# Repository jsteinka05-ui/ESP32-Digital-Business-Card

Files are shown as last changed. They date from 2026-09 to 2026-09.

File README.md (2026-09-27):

# ESP32 Digital Business Card

A standalone digital business card built around a **Seeed Studio XIAO ESP32-C3** and a **3.5-inch ILI9488 SPI TFT display**. This repository documents its hardware and a firmware rewrite in **C using ESP-IDF**.

The device is designed to display personal contact information and a LinkedIn QR code, with a single button for slide navigation, display recovery, and wake-up.

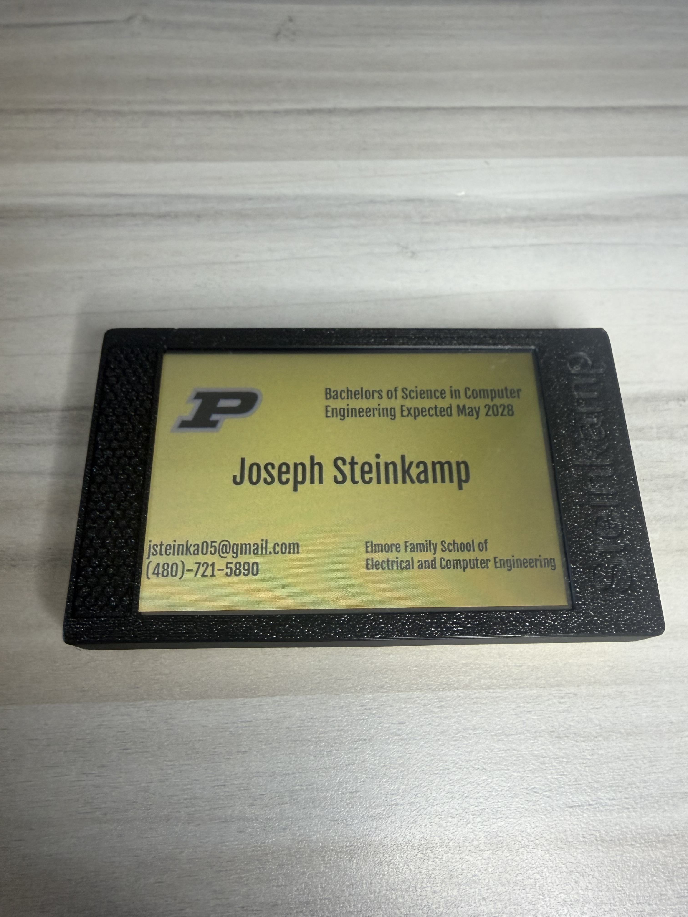
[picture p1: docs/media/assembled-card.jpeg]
Assembled digital business card displaying contact information in its printed enclosure


[Watch the device demonstration](docs/media/device-demo.mp4) — slide transitions, LCD power switching, and display recovery.

## Project Status

The custom PCB assembly, wiring, printed enclosure, and C firmware rewrite are complete. The ESP-IDF v6.1 firmware supports debounced button input, embedded slides, animated navigation, LCD recovery, and five-minute inactivity sleep with button wake.

Functional hardware checks and a clean-checkout build are complete. Recorded results include five startup draws at 238 ms each and twenty transitions averaging 2,604.75 ms, with unchanged sampled free heap. See the [validation record](docs/testing.md) for methods and limits. Current consumption and physical wake latency are outside this release's measurement scope.

Hardware design files and printable enclosure models are available under [hardware/](hardware/README.md).

## Features

- Business-card and LinkedIn QR-code slides.
- Standalone operation with images embedded in firmware; no network connection or SD card required.
- Animated transitions controlled by a physical button.
- Long-press recovery after the LCD is power-cycled independently of the microcontroller.

- Low-power idle after five minutes without button input.
- Button wake-up that restores the current slide without advancing it.

The current backlight is powered directly from the display supply. Automatic backlight shutdown would require a hardware change. Wi-Fi and Bluetooth Low Energy are future expansion options.

## Hardware and Design Choices

| Part | Purpose |
|---|---|
| Seeed Studio XIAO ESP32-C3 | Compact controller with flash storage, SPI, and room for wireless expansion |
| 3.5-inch ILI9488 SPI TFT | Color contact-information and QR-code display |
| Momentary pushbutton | Navigation, display recovery, and wake-up |
| LCD power switch | Controls LCD power independently of the microcontroller |

The ESP32-C3 can be considered overkill for displaying two images and reading a button. I chose it to leave room for future Wi-Fi and Bluetooth Low Energy functionality without replacing the controller.

Embedded images keep the initial storage design simple, while SPI limits the display wiring. The tradeoffs include flash usage, display-update bandwidth, and the need to rebuild firmware when artwork changes.

See the [design document](docs/design.md) for component rationale, wiring, memory calculations, and power-management considerations.

## Intended Controls

The firmware rewrite targets the following controls, including sleep and wake behavior:

| Input or condition | Intended behavior |
|---|---|
| Short press: less than 900 ms | Advance to the next slide upon release |
| Long press: at least 900 ms | Reinitialize the LCD and redraw the current slide upon release |
| Five minutes without button input | Enter a low-power idle state |
| Button press while idle | Wake and restore the current slide; consume the gesture without navigation |

The LCD switch leaves the ESP32-C3 running. Display recovery is needed because restoring LCD power does not automatically repeat the panel initialization sequence.

Button-only wake-up assumes the LCD supply switch remains on. If the LCD is manually switched off, restore its power before waking the device or requesting display recovery.

## Repository Layout

```text
firmware/                 ESP-IDF application and build configuration
    main/                 Application logic
    components/ili9488/   Display driver
    images/               Source artwork and display assets
    tools/                Image conversion utilities
hardware/                 Hardware documentation
    schematic/            KiCad project, PCB, schematic, and local libraries
    manufacturing/        Versioned Gerber and drill packages
    enclosure/            Printable STL models and enclosure notes
docs/                     Design decisions and testing documentation
.github/workflows/        Future automated build checks
```

## Development Setup

The intended development environment is:

- VS Code with Espressifâ€™s ESP-IDF extension.
- ESP-IDF with the ESP32-C3 target and its toolchain.
- A USB data connection to the XIAO ESP32-C3.
- Python with Pillow for artwork conversion; the saved RGB assets allow firmware builds without Pillow.

Firmware development takes place under `firmware/`. The application includes debounced input, streamed image drawing, and slide navigation. The [progress log](docs/progress.md) distinguishes implemented features from verified hardware behavior.

## Roadmap

- [x] Establish repository structure and ignore rules.
- [x] Document the initial design.
- [x] Complete prototype wiring, custom PCB assembly, and printed enclosure.
- [x] Organize KiCad files, manufacturing exports, and enclosure models.
- [x] Implement startup logging and debounced button input.
- [x] Initialize the display and verify drawing, colors, and orientation.
- [x] Display embedded slides and implement navigation.
- [x] Add LCD recovery and animated transitions.
- [x] Implement inactivity sleep and button wake-up.
- [x] Verify sleep/wake on hardware.
- [x] Publish build instructions, test results, and a device demonstration.

## Documentation

- [Firmware rewrite design](docs/design.md): architecture, hardware selection, interaction rules, and validation plan.
- [Firmware validation](docs/testing.md): build checks, simulated button tests, and hardware results.
- [Firmware development plan](docs/firmware-plan.md): implementation stages and completion criteria.
- [Hardware](hardware/README.md): KiCad project, parts inventory, and manufacturing revisions.
- [Enclosure](hardware/enclosure/README.md): top case, bottom case, and button models.
- [Progress and commit log](docs/progress.md): milestones, checks, and commit references.

## License

Third-party library sources and licensing are listed in the [library documentation](hardware/schematic/libraries/README.md), with the upstream license included alongside its files.

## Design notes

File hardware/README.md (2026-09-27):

# Hardware

The digital business card uses a custom PCB and a three-part printed enclosure. PCB assembly, wiring, and the physical prototype are complete.

## Directory Layout

```text
schematic/
    Project_Buisiness_Card.kicad_pro  KiCad project
    Project_Buisiness_Card.kicad_sch  Circuit schematic
    Project_Buisiness_Card.kicad_pcb  PCB layout
    fp-lib-table                    Footprint libraries
    sym-lib-table                   Symbol libraries
    Library.pretty/                 Custom footprint library
    libraries/                      XIAO symbols and footprints
manufacturing/
    Buisiness_Card_Gerbers_1.2.zip
    Buisiness_Card_Gerbers_1.3.zip
    Project_Buisiness_Gerbers_1.4.zip
enclosure/
    Top_Case.stl
    Bottom_Case.stl
    Button (1).stl
```

The schematic, PCB, and project settings share a directory and base name so KiCad can associate them as one project.

## KiCad Project

Open [Project_Buisiness_Card.kicad_pro](schematic/Project_Buisiness_Card.kicad_pro) in KiCad 9.0. The XIAO libraries are stored locally and use project-relative paths.

The PCB uses a custom through-hole XIAO footprint. The original surface-mount footprint is available under a separate library name. The active assignment uses the through-hole version.

[Library documentation](schematic/libraries/README.md) describes the footprint variants, project assignments, and upstream sources.

## Fabricated PCB

Bare revision 1.4 PCB before component installation. The component side shows the XIAO footprint, display header, passive-component positions, and button and power-switch connections.

| Component side | Reverse side |
|---|---|
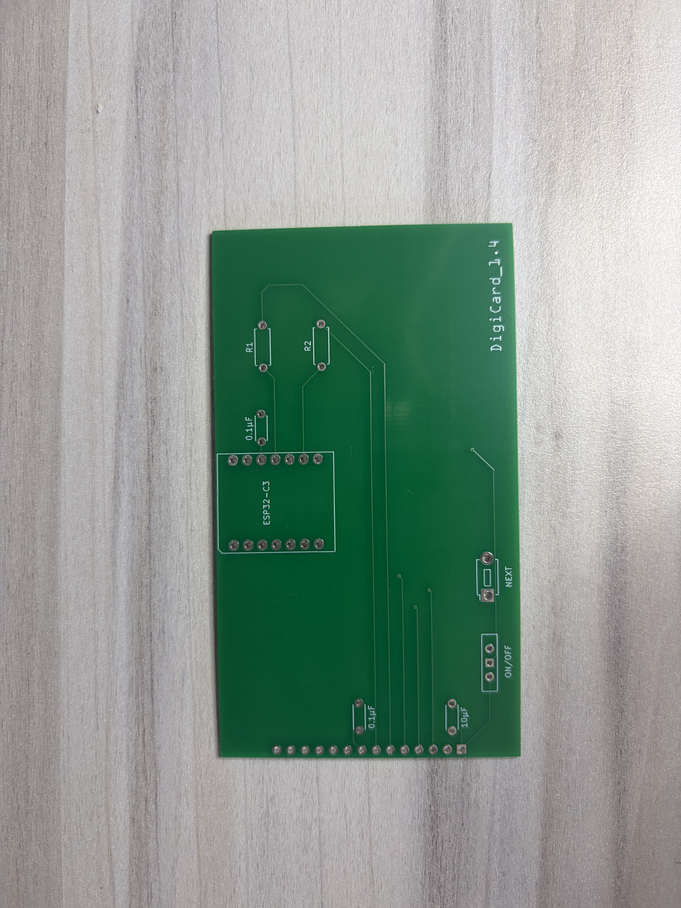
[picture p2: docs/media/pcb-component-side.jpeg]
Bare revision 1.4 PCB component side with labeled through-hole footprints
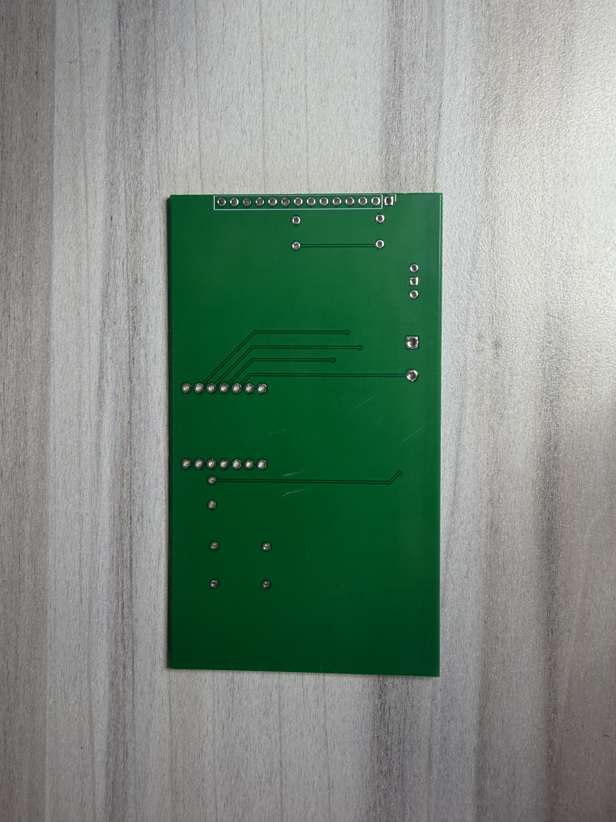
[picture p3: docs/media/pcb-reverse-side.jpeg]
Reverse side of the bare PCB showing routing and through-hole pads
|  |  |

## Manufacturing Files

Version **1.4** is the current hardware revision. Versions 1.2 and 1.3 are retained as earlier exports. Each archive contains Gerber layers and plated/non-plated drill files.

## Enclosure

The enclosure consists of a [top case](enclosure/Top_Case.stl), [bottom case](enclosure/Bottom_Case.stl), and [button](<enclosure/Button (1).stl>).

See the [enclosure documentation](enclosure/README.md) for the printable models.

## Components

| Component | Quantity | Function |
|---|---:|---|
| Seeed Studio XIAO ESP32-C3 | 1 | Display control and button processing |
| 3.5-inch ILI9488 SPI TFT | 1 | Contact-information and QR-code display |
| SPST slide switch | 1 | LCD power control |
| Momentary pushbutton | 1 | Slide navigation and display recovery |
| 1 × 14 header, 2.54 mm pitch | 1 | LCD connection |

## Schematic Values and Footprint Assignments

These entries describe the KiCad design. Switch model names identify the assigned footprints.

| Reference | Schematic value | Footprint |
|---|---|---|
| U1 | XIAO ESP32C3 | Project-specific through-hole XIAO footprint |
| SW1 | SW_SPST | Wuerth WS-SLTV slide-switch footprint |
| SW2 | SW_Push | APEM MJTP1243 pushbutton footprint |
| J_LCD1 | Conn_01x14 | 1 × 14 pin header, 2.54 mm pitch |
| J_BAT1 | Two-pin connector | — |
| C1, C3 | 0.1 µF | Radial capacitor, 5 mm lead spacing |
| C2, C4 | 10 µF | Radial capacitor, 5 mm lead spacing |
| R4, R6 | `46` | Axial resistor, 7.62 mm lead spacing |

The [design specification](../docs/design.md#existing-prototype-wiring) contains the GPIO mapping and LCD power behavior.

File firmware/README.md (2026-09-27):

# Firmware

C firmware for the Seeed Studio XIAO ESP32-C3, developed with ESP-IDF v6.1.

## Current Behavior

At startup, the application initializes the LCD, validates both embedded images, and displays the business card. A short release advances with a black wipe and shuffled tile reveal. A long release reinitializes the LCD and redraws the selected slide without advancing it. The previous slide firmware and QR appearance were tested on the board; this recovery/animation version has been flashed and passed hardware checks for recovery, transitions, gesture suppression, QR scanning, and timing.

The button module configures GPIO6 as an input with an internal pull-up. The application accepts transitions after 30 ms of stable input. It samples once per loop, with a 10 ms task delay plus any drawing work. Animation steps are bounded; actual sampling gaps are logged for hardware measurement.

| Serial message | Meaning |
|---|---|
| `Button input ready` | GPIO initialization succeeded |
| `Button pressed` | A press passed the debounce interval |
| `Short press released` | A tracked press lasted less than 900 ms |
| `Long press released` | A tracked press lasted at least 900 ms |
| `Button released (no tracked press)` | A button held at startup was released without generating a gesture |

Durations are measured between accepted press and release transitions. A tracked release emits the short or long event instead of a separate release event. Holding never repeatedly emits a gesture. The first reading establishes state without generating a button event.

The button module returns events; the application controller decides whether to start a transition or recover the LCD. Accepted events during animation update the activity timestamp but never queue navigation or recovery. After startup, animation, or recovery, input must remain released for 30 ms before another gesture is accepted. After 300 seconds without accepted input, the power manager requests panel sleep and enters ordinary light sleep. Hardware sleep/wake validation is complete.

Normal transitions return to button sampling after one eight-row wipe strip or at most sixteen 8 x 8 tiles. The next step is eligible after 10 ms; a delayed loop never catches up with an unbounded batch. Each reveal covers all 2,400 tiles once. The selected slide changes only after the last tile succeeds.

Panel reset delays, startup drawing, and recovery drawing remain synchronous. A complete gesture during those operations can be missed; a held button is consumed until release. Drawing errors stop the transition and preserve the selected index. The screen may remain partial until a later successful transition or long-press recovery.

## Inactivity and Wake

The inactivity interval starts after the initial image is drawn. Accepted button events restart it, including events suppressed during animation. Sleep is deferred while a button is held, input is blocked, or rendering is active.

At timeout, the panel receives display-off and sleep-in commands. The application keeps polling for 120 ms while the panel settles. A press during that interval cancels sleep and restores the selected slide. Otherwise, the ESP32-C3 enters ordinary light sleep with active-low GPIO6 wake and its pull-up retained. Peripheral power-down sleep is not supported by this configuration.

Wake reinitializes the panel on the existing SPI bus and redraws the selected slide. The wake gesture is consumed until the button has remained released for 30 ms, even if held longer than 900 ms. The inactivity timer restarts after restoration. A rejected sleep attempt also restores the panel; errors are logged and the timeout restarts rather than retrying continuously.

The backlight remains powered because it is wired directly to the display supply. The manual LCD switch must remain on for button-only wake. Current consumption and physical wake latency are outside this release's measurement scope. The logged redraw time covers panel initialization and drawing, not the complete physical wake latency.

## Build, Flash, and Monitor

Install ESP-IDF v6.1 with the ESP32-C3 tools. In VS Code, open this `firmware` directory, select the installed ESP-IDF environment, and open an ESP-IDF terminal here.

```text
idf.py build
idf.py -p <PORT> flash monitor
```

Replace `<PORT>` with the board's serial port selected through `ESP-IDF: Select Port to Use`. On Windows this is a COM port; its number varies by computer. Close other serial monitors before flashing. Exit the monitor with Ctrl+].

The project selects the ESP32-C3 target. `sdkconfig.defaults` specifies 4 MB flash, the USB Serial/JTAG console, and the custom partition table. `partitions.csv` provides a 2 MB factory application partition for code and embedded images. The remaining flash is unallocated; OTA is not configured. Flashing replaces the firmware currently on the board.

Existing checkouts with a generated `sdkconfig` retain their old settings. In `idf.py menuconfig`, select **Partition Table > Custom partition table CSV** and use `partitions.csv`, then rebuild. Flash with `idf.py flash` so the updated partition table is written along with the application.

## Images and Diagnostics

Both source PNGs and generated RGB files are tracked in [images/](images/README.md). Conversion is a separate step, so building saved assets does not require Pillow. After editing artwork, regenerate the matching RGB file before building.

To run the earlier color and corner checks, enable **Business card > Run display diagnostics before showing slides** in `idf.py menuconfig`. The corner pattern remains visible for five seconds before the business-card slide appears. This option defaults off.

Startup logs the initial drawing duration. Each ended transition logs its elapsed time and longest observed input-sampling interval, including the final step and task delay. Heap readings are logged after startup and transitions. Recovery logs the restored slide. Hardware measurements belong in the validation record.

## Source Layout

- `main/main.c`: startup, input polling, and timing/memory logging.
- `main/app_controller.c` and `main/app_controller.h`: selected slide, gesture suppression, activity tracking, and LCD recovery.
- `main/power_manager.c` and `main/power_manager.h`: inactivity timeout, panel settling, and GPIO light-sleep wake.
- `main/transitions.c` and `main/transitions.h`: incremental wipe, shuffled tile ordering, and bounded drawing steps.
- `main/slides.c` and `main/slides.h`: flash image references, length validation, indexed drawing, and region extraction.
- `main/button.h`: public button interface.
- `main/button.c`: GPIO configuration, raw readings, debouncing, and gesture classification.
- `main/display_diagnostics.c`: bounds checks, color fills, and the corner pattern.
- `components/ili9488/`: SPI transport, panel setup, and bounded drawing; see its [driver documentation](components/ili9488/README.md).

## Validation

The firmware builds with ESP-IDF v6.1. Simulated tests cover debounce timing, contact bounce, the 899/900/901 ms classification boundary, long holds, startup-held input, and reinitialization. The earlier button firmware was verified on the assembled board. The image renderer passes simulated transfer/error checks and the application passes simulated navigation checks. The Python converter tests run with `python -m unittest discover -s tools/tests -v`. Integrated simulated checks use the actual button logic and cover recovery, suppressed gestures, complete tile coverage, final pixels, and failure handling. Recovery, repeated transitions, gesture suppression, QR scanning, and timing/memory checks also passed on the assembled board. Sleep tests cover timeout boundaries, entry cancellation, wake-gesture suppression, repeated restoration, and errors with simulated peripherals. Functional hardware sleep/wake checks passed; current consumption and physical wake latency are outside this release's measurement scope. See the [validation record](../docs/testing.md) for scope and results.

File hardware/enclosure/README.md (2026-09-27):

# Printed Enclosure

The working prototype uses a 3D-printed enclosure with separate top, bottom, and button pieces. The models are provided as STL meshes.

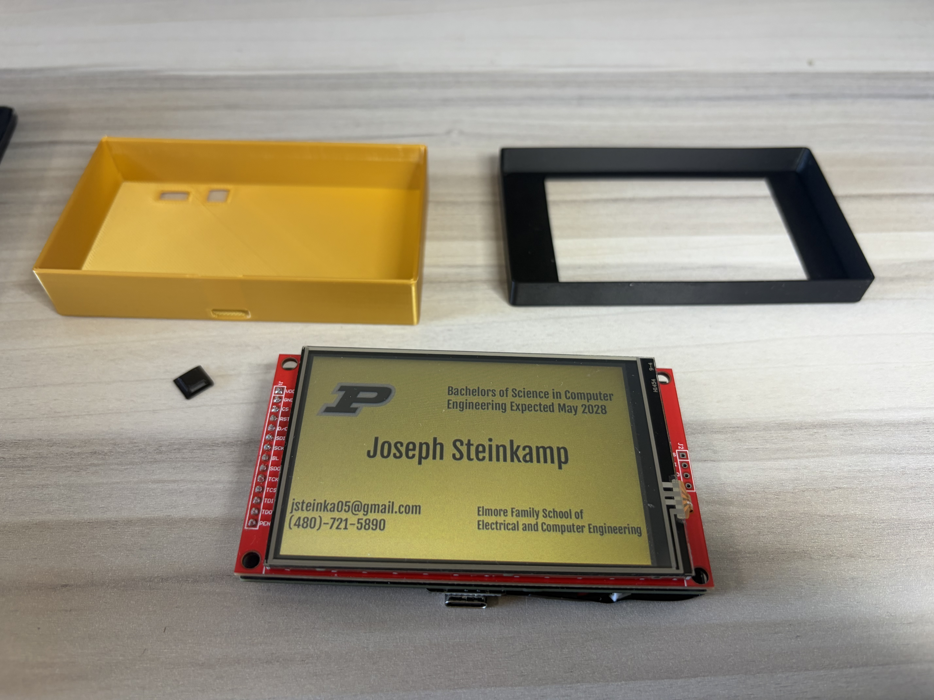
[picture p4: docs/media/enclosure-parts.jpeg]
Yellow bottom case, black screen bezel, separate button piece, and powered display assembly


The enclosure disassembled: bottom case, screen bezel, button piece, and powered display assembly.

## Models

| File | Part |
|---|---|
| [Top_Case.stl](Top_Case.stl) | Top enclosure section |
| [Bottom_Case.stl](Bottom_Case.stl) | Bottom enclosure section |
| [Button (1).stl](<Button (1).stl>) | Separate button piece |

## Hardware Integration

The enclosure forms the physical housing for the display and custom PCB. The button piece provides the external interface to the momentary switch used for navigation and LCD recovery.

The [hardware overview](../README.md) covers the electronics, and the [design specification](../../docs/design.md#user-interaction) defines the button controls.

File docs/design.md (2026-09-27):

# Digital Business Card — Firmware Rewrite — Design Specification

## Overview

This project is a standalone digital business card built around a Seeed Studio XIAO ESP32-C3 and a 3.5-inch ILI9488 SPI TFT display. A working physical prototype with a 3D-printed enclosure has been completed, and a custom PCB is already implemented.

This document defines the architecture, intended behavior, and acceptance criteria for the firmware rewrite in C using ESP-IDF. The rewrite will preserve the device’s slide display, button navigation, animated transitions, and LCD recovery behavior while improving software organization and validation.

A five-minute inactivity timeout uses display sleep and ordinary ESP32-C3 light sleep with GPIO6 button wake. The implementation passes software and hardware checks, including sleep/wake behavior. Current consumption and physical wake latency are outside this release's measurement scope. The directly powered backlight stays on.

The physical prototype, wiring, and custom PCB assembly are complete. This specification covers the replacement firmware and its low-power feature.

## Project Goals

- Display contact information and a scannable LinkedIn QR code without a computer or network connection.
- Provide a simple interface using one physical button.
- Support animated transitions between slides.
- Recover the LCD after it is power-cycled independently of the microcontroller.
- Enter a low-power state after five minutes without button input.
- Restore the current slide when awakened.
- Maintain a modular and reproducible firmware project.
- Preserve the possibility of future Wi-Fi and Bluetooth Low Energy features.

Wireless functionality is outside the initial implementation scope.

## Hardware Selection

### Seeed Studio XIAO ESP32-C3

The XIAO ESP32-C3 combines a compact development board with sufficient processing capability, storage, and interfaces for this project.

Relevant specifications include:

- Approximately 21 × 17.8 mm board footprint.
- Single-core, 32-bit RISC-V processor operating at up to 160 MHz.
- 400 KB of on-chip SRAM.
- 4 MB of onboard flash.
- 2.4 GHz Wi-Fi.
- Bluetooth Low Energy.
- SPI and general-purpose input/output support.

The ESP32-C3 can be considered overkill for displaying two images and handling a button input. I chose it because I wanted the possibility of expanding the project through Wi-Fi and Bluetooth Low Energy without replacing the microcontroller.

Potential extensions include wireless content updates, configuration through a local web interface, and BLE-based interaction. The existing device operates offline, and the initial firmware rewrite will retain that behavior.

Its small footprint also limits the space occupied by the control electronics behind the display.

Reference: [Seeed Studio XIAO ESP32-C3 documentation](https://wiki.seeedstudio.com/XIAO_ESP32C3_Getting_Started/)

### ILI9488-Based 3.5-Inch TFT Display

The display provides space for readable contact information, personal artwork, and a substantial QR code. Color output and animated transitions support the intended visual presentation.

The display is held in landscape orientation, with artwork designed at 480 × 320 pixels.

SPI reduces signal wiring compared with a parallel display interface. The tradeoff is limited transfer bandwidth, which affects full-screen updates and animation speed.

The TFT backlight also consumes power during viewing. This design prioritizes color and animation, with power management intended to reduce consumption when the device is inactive.

Reference: [Example ILI9488 SPI module documentation](https://lcdwiki.com/3.5inch_SPI_Module_ILI9488_SKU%3AMSP3520)

### Momentary Pushbutton

A single momentary button provides navigation and display recovery. The planned low-power feature will also use this button for wake-up.

The button connects GPIO6 to ground and uses the microcontroller’s internal pull-up. The input reads high when released and low when pressed.

This arrangement reduces external components and keeps the interface simple. The implemented input module requires 30 ms of unchanged input before accepting a transition. It samples approximately every 10 ms and measures gesture duration between accepted press and release transitions. A button held at startup must be released before a new gesture can be tracked.

### LCD Power Switch

The hardware arrangement includes a switch that controls LCD power while leaving the ESP32-C3 running.

Removing LCD power causes the display controller to lose its configuration. Restoring that power does not automatically restart the application or initialize the panel.

The device provides a long-press recovery action that resets the LCD and redraws the current slide. The replacement firmware will preserve this behavior.

This switch does not provide whole-device shutdown. A future hardware revision may change the power arrangement.

## Existing Prototype Wiring

The assembled PCB uses the following connections. This pin mapping is the hardware interface for the firmware rewrite.

| Signal | ESP32-C3 GPIO or connection |
|---|---|
| LCD SCK | GPIO8 |
| LCD MOSI / SDI | GPIO10 |
| LCD MISO / SDO | Disconnected |
| LCD CS | GPIO4 |
| LCD DC / RS | GPIO5 |
| LCD RESET | GPIO3 |
| Button | GPIO6 to ground |
| LCD VCC | 3.3 V through the LCD power arrangement |
| LCD backlight | 3.3 V display supply; no software switching |
| LCD ground | Common ground with the microcontroller |

## Software Platform

The replacement firmware will use C and ESP-IDF.

C supports direct work with memory, pointers, structures, and bit operations. ESP-IDF provides the GPIO, SPI, timing, FreeRTOS, and power-management facilities required by the design.

ESP-IDF also provides a path to future networking features without changing frameworks.

Local and automated builds will use the same ESP-IDF version.

## Repository Organization

The project separates firmware, hardware documentation, and design records:

```text
firmware/
    main/
    components/ili9488/
    images/
    tools/
hardware/
    schematic/
    manufacturing/
    enclosure/
docs/
.github/
    workflows/
```

The firmware directory will contain the ESP-IDF build configuration. Hardware files will describe the physical assembly, while `docs/` will contain design decisions, testing procedures, and development notes.

## Software Architecture

| Module | Responsibility |
|---|---|
| Application | Startup, current slide, operating state, and event handling |
| Button | Debouncing, duration measurement, and input events |
| Display driver | SPI communication, panel initialization, and drawing |
| Slides | Embedded image references and slide metadata |
| Transitions | Animated changes between slides |
| Power management | Inactivity tracking, sleep entry, and wake restoration |
| Image conversion tool | Conversion of source artwork into display-ready bytes |

Modules will be introduced as functionality develops.

Only one execution context will control the display at a time. Drawing, recovery, and sleep operations must not issue overlapping panel commands.

Display communication setup and panel initialization will be separate operations. Startup requires both; LCD recovery should reuse the existing SPI connection.

## Image Storage and Rendering

### Embedded Assets

The replacement firmware will retain the two-image embedded storage approach used by the existing device.

For a small, fixed slide set, this avoids an SD card, additional storage wiring, and a runtime filesystem.

The tradeoffs are that artwork changes require rebuilding and flashing, and raw images occupy significant flash space.

### Pixel Format and Memory

Each full-screen RGB image contains:

320 × 480 × 3 = 460,800 bytes

Two images require 921,600 bytes before application overhead.

Assets will use RGB888 storage: one byte each for red, green, and blue. The display will be configured for RGB666 transmission, retaining the upper six bits of each channel while sending three bytes per pixel.

One complete image exceeds the microcontroller’s total internal SRAM capacity. The renderer will therefore stream data from flash through small reusable buffers.

Image lengths and drawing bounds are validated before transmission. The current renderer streams one row at a time through a shared 960-byte buffer and leaves the source image unchanged. QR recoloring uses an additional 960-byte stack row to blend a translucent white panel over the business card's gold background while preserving the black modules.

Both RGB assets are embedded in the application flash image. A 2 MB factory application partition accommodates the 921,600 bytes of artwork plus firmware; the remaining space in the 4 MB flash is unallocated. OTA partitions are outside the current design.

### Orientation

The replacement renderer will initially retain native 320 × 480 panel coordinates with pre-rotated landscape artwork:

```text
480 × 320 landscape artwork
    → rotate counter-clockwise
    → store 320 × 480 RGB bytes
    → stream to the display
```

The converter requires exactly 480 × 320 source pixels and performs a lossless quarter-turn without resizing. Transparent artwork is composited onto white. Source PNGs and converted RGB assets are tracked together.

Color fills and corner markers established the mounted orientation: blue top-left, red top-right, white bottom-left, and green bottom-right. The revised QR appearance has been confirmed on the display. Physical QR scanning passed after transition and recovery testing.

### SPI Performance

The replacement firmware will initially retain SPI mode 0 at 20 MHz, with operation revalidated on the target hardware.

At that rate, a complete image requires approximately 184 ms of pixel transfer alone:

460,800 × 8 ÷ 20,000,000 ≈ 0.184 seconds

Command transfers and software overhead increase the actual duration. Animations will account for this bandwidth limit.

## User Interaction

The replacement firmware preserves slide navigation and LCD recovery while adding inactivity tracking and defined input handling during animation.

### Startup

The application will:

1. Configure the button.
2. Initialize SPI and the LCD.
3. Display the business-card slide.
4. Begin processing input and tracking inactivity.

Panel reset and initialization delays will follow the applicable hardware requirements and be validated through repeated startup tests.

### Short Press

A debounced press lasting less than 900 ms will advance to the next slide upon release.

Navigation will wrap from the final slide to the first slide.

Normal slide changes will not reset the LCD.

### Long Press

A debounced press lasting at least 900 ms will trigger LCD recovery upon release.

Recovery will reset and configure the panel, redraw the current slide, and leave the slide index unchanged.

Each long press must produce exactly one recovery action and no navigation action.

### Input During Animation

Button input during an animation will update inactivity tracking but will not queue additional slide changes.

A gesture beginning during an animation must be released before another navigation gesture is accepted. This avoids unexpected actions when the animation finishes. The controller requires 30 ms of released input after drawing before rearming, including for a press first sampled just after the final animation step.

Transitions wipe eight native rows per step, then reveal at most sixteen shuffled 8 × 8 tiles per step. The 2,400-entry ordering array uses 4,800 bytes and is reused for each transition. A 192-byte tile buffer obtains the same composed pixels used by full-screen drawing. Each step is eligible after 10 ms and returns to input sampling without catching up on missed steps. Actual loop timing is measured on the board.

The current slide index changes only after successful completion. A failed transfer stops the transition and preserves the previous selection for recovery. Startup and recovery still use synchronous full-screen drawing; gestures during panel reset and redraw are not queued.

## Low-Power Idle State

Low-power idle is implemented with a separate power manager and serialized display operations.

### Inactivity Detection

The device will enter a low-power idle state after 300 seconds without valid button input.

The timer begins after the initial slide is displayed. Each debounced press or release updates the activity timestamp.

Sleep entry will be deferred while:

- The button is held.
- An animation is running.
- Display recovery is in progress.

### Sleep Entry

When the inactivity timeout expires, the application will:

1. Wait until rendering has finished and the button is stably released.
2. Preserve the current slide selection.
3. Send ILI9488 display-off (`0x28`) and sleep-in (`0x10`).
4. Continue polling for 120 ms while the panel settles.
5. Enter ordinary ESP32-C3 light sleep with low-level GPIO6 wake enabled.

A press during settling cancels entry and restores the selected slide. The GPIO pull-up remains active during sleep. Wake, cancellation, or a rejected sleep attempt triggers panel reinitialization and redraw through the existing SPI bus. Restoration restarts the inactivity interval, including after an error, to avoid continuous retries. Hardware sleep/wake validation is complete.

### Backlight Control

The existing backlight connection has no software-controlled switching.

The manual LCD power switch removes display and backlight power. The processor cannot restore a mechanically switched supply. Automatic backlight shutdown requires a controllable power path; display sleep alone does not provide that control.

### Wake-Up

Pressing the button while idle will wake the device and restore the previously displayed slide.

This button-only behavior assumes the LCD supply switch remains on. If the LCD has been manually switched off, restore its supply before waking the device. If the processor is already awake when LCD power is restored, use long-press recovery. Wake restoration must reinitialize the panel when its state has been lost.

The wake-up gesture will be consumed entirely as a wake action. It will not advance the slide or trigger recovery, regardless of how long it remains held.

The application will wait for a stable release before accepting another gesture and restart the inactivity timer.

### Sleep-Mode Evaluation

Ordinary light sleep is the initial approach because it retains application state and supports the existing GPIO6 button with the GPIO peripheral powered.

ESP32-C3 GPIO wake from deep sleep is limited to GPIO0–5. GPIO6 therefore does not support this button wake in deep sleep. Peripheral power-down light-sleep configurations have the same restricted wake-pin requirement and are outside the initial implementation.

Panel restoration passed on the assembled board. Ordinary light-sleep consumption and physical wake latency are outside this release's measurement scope. See [ESP-IDF sleep modes](https://docs.espressif.com/projects/esp-idf/en/v6.1/esp32c3/api-reference/system/sleep_modes.html) and the [ESP32-C3 GPIO capability definitions](https://github.com/espressif/esp-idf/blob/v6.1/components/soc/esp32c3/include/soc/soc_caps.h).

Active current, idle current, and wake-up latency are the power-management performance metrics.

## QR-Code Presentation

The QR slide will link to the LinkedIn profile and include a clear description of its purpose.

Scanning will be tested on the physical screen under documented viewing conditions.

## Validation Plan

The following acceptance checks define completion of the replacement firmware on the assembled hardware.

| Area | Acceptance check |
|---|---|
| Startup | Repeated full power cycles display the initial slide |
| Short press | One deliberate press advances exactly one slide |
| Long press | Recovery occurs once without changing slides |
| Debouncing | Contact bounce does not generate extra actions |
| Orientation | Corners and color patches appear correctly |
| Rendering | Invalid sizes and drawing bounds are rejected |
| Animation | Each transition finishes with the correct image |
| LCD recovery | Recovery restores the slide after LCD-only power cycling |
| QR code | The displayed code scans reliably |
| Inactivity | Idle begins after approximately 300 seconds without input |
| Timer reset | Valid input restarts the inactivity interval |
| Held button | The device does not sleep while the button is held |
| Wake-up | The previous slide returns without unintended navigation |
| Repeated sleep | Multiple sleep/wake cycles remain reliable |
| Power | Functional sleep/wake verified; current reduction is not quantified |
| Reproducibility | A fresh checkout builds using the documented toolchain |

## Development Milestones

### Existing Hardware and Prototype Work

- Working physical prototype completed, including slide display, navigation, transitions, and LCD recovery.
- 3D-printed enclosure completed.
- Prototype wiring and custom PCB assembly completed; the PCB is implemented in the working device.

### Firmware Rewrite and Remaining Integration

The [firmware development plan](firmware-plan.md) groups the following work into stages F1–F7, corresponding to repository Steps 2–8.

1. Establish repository structure and hardware documentation.
2. Build minimal firmware with startup logging.
3. Implement debounced button input and press classification.
4. Initialize the LCD and display solid colors.
5. Implement bounded drawing operations.
6. Convert, embed, and display one image.
7. Add the second slide and navigation.
8. Implement independent LCD recovery.
9. Add animated transitions.
10. Evaluate backlight control and processor sleep.
11. Implement inactivity detection and wake-up.
12. Verify replacement-firmware operation on the completed custom PCB assembly.
13. Measure performance and document the completed device.

## Future Expansion

Possible extensions include wireless configuration, Wi-Fi content updates, BLE interaction, additional slides, and further PCB or enclosure revisions.

These features remain outside the firmware rewrite’s initial scope. The hardware selection leaves room to explore them after the replacement firmware and planned power-management feature are complete.

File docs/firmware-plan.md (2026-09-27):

# Firmware Development Plan

## Current Progress

The hardware and firmware implementation are complete. Functional hardware acceptance, including reset, repeated cold starts, display diagnostics, navigation, recovery, and sleep/wake, is complete. The clean-checkout build workflow is confirmed. Timing and memory measurements are recorded, and device photographs and a demonstration are included. Current consumption and physical wake latency are outside this release's measurement scope.

Development proceeds through seven firmware stages. Each stage produces a working increment, validation evidence, and a focused commit. Firmware stage F1 corresponds to Step 2 in the [progress log](progress.md); Step 1 records the hardware and repository baseline.

## Milestones

| Stage | Repository step | Deliverable | Completion criterion | Status |
|---|---|---|---|---|
| F1 | 2 | Minimal ESP-IDF application | Builds for ESP32-C3, logs periodically, and restarts correctly | Complete |
| F2 | 3 | Button input and gesture events | Debounced short/long events occur once per gesture, classified on release | Complete |
| F3 | 4 | Display driver and bounded drawing | Repeated startup, color fills, corner markers, and rectangle bounds pass | Complete |
| F4 | 5 | Embedded images and slide navigation | Two correctly oriented slides cycle reliably and the displayed QR scans | Complete |
| F5 | 6 | LCD recovery and incremental animation | Recovery preserves the slide; transitions maintain input tracking | Complete |
| F6 | 7 | Inactivity and light sleep | A 300-second timeout enters sleep; button wake restores the slide without navigation | Complete |
| F7 | 8 | Release validation | Clean-checkout build, repeatable hardware tests, and measured results | In progress |

## Implementation Approach

- Use C with ESP-IDF and pin the tested framework version at F1.
- Keep application decisions separate from GPIO sampling and display transfers.
- Begin with one application task and synchronous display operations. At F5, advance animations in bounded steps between input samples.
- Store images in flash and stream them through a reusable transfer buffer.
- Keep panel reset/configuration separate from SPI bus creation.
- Preserve the existing native portrait image layout, GPIO mapping, and initial 20 MHz SPI configuration.
- Introduce modules and automated checks alongside the behavior they support.

## F1 — Application Foundation

Establish the root and main-component build files under `firmware/`, implement startup and periodic logging, and select the ESP32-C3 target. Record the tested ESP-IDF version and a repeatable build/flash workflow. No LCD or button code is required for this milestone.

Evidence: successful build, serial output, and reset/power-cycle behavior.

## F2 — Input Handling

Implement stable press/release detection and duration-based gesture events. A short press is less than 900 ms; a long press is at least 900 ms. Classification occurs on release. Separate the timestamp-driven input logic from the hardware read so boundary and bounce cases can be exercised deterministically.

Evidence: button test cases, event counts, and synthetic tests around the classification threshold.

## F3 — Display Driver

Add the ILI9488 component with command/data transfers, panel initialization, address windows, and bounded rectangle drawing. Establish color order and orientation with a diagnostic pattern before displaying artwork.

Evidence: repeatable cold starts, correct corner/color pattern, and invalid-coordinate rejection.

## F4 — Images and Navigation

Add the image converter, source artwork, embedded RGB assets, and slide metadata. Stream through a small buffer; reject incorrect image lengths. Integrate short-press navigation with immediate redraws before introducing animation.

Evidence: conversion checks, flash/heap measurements, correctly oriented slides, and a physical QR scan.

## F5 — Recovery and Animation

First implement long-press panel recovery without recreating the SPI bus. Then add the wipe and tile transition as incremental operations with input sampling between steps. Gestures during an animation update activity but do not queue navigation; release is required before accepting another gesture.

Evidence: independent LCD power-cycle recovery, repeated transitions, and defined behavior for presses during animation.

## F6 — Inactivity and Sleep

The inactivity state machine uses ordinary light sleep with GPIO6 wake-up and the GPIO peripheral retained. Panel settling remains nonblocking for 120 ms, allowing button input to cancel sleep entry. ESP32-C3 deep-sleep GPIO wake is limited to GPIO0–5, so it is not the initial approach for the existing button connection.

The final timeout is 300 seconds. Wake consumes the entire initiating gesture and restores the current slide. Sleep is deferred during a held button, drawing, or recovery.

The current backlight remains connected to the display supply. Processor/display sleep and automatic backlight power switching are separate capabilities. Button-only wake assumes the manual LCD switch remains on.

Evidence: full-duration timeout tests, repeated wake cycles, and gesture suppression. Current consumption and physical wake latency are not quantified for this release.

## F7 — Release Validation

Run the acceptance matrix in the [design specification](design.md#validation-plan). Build from a clean checkout using the recorded toolchain and add an automated build check. Publish actual test results, resource measurements, build instructions, and a device demonstration.

Evidence: clean-checkout and automated builds, hardware results tied to a firmware revision, and the release demonstration.

## Commit and Documentation Policy

Each implementation commit includes its relevant documentation and test changes. Milestones may span multiple commits when they contain independently verifiable behavior, particularly input handling, display bring-up, recovery, and sleep.

The [progress log](progress.md) records completed stages and commit references. `firmware/README.md` contains the build instructions; [docs/testing.md](testing.md) records build, simulated-input, and hardware validation results. A successful build establishes compilation, while hardware behavior is recorded separately.

## Technical References

- [ESP-IDF getting started](https://docs.espressif.com/projects/esp-idf/en/v6.1/esp32c3/get-started/index.html)
- [Build system](https://docs.espressif.com/projects/esp-idf/en/v6.1/esp32c3/api-guides/build-system.html)
- [GPIO](https://docs.espressif.com/projects/esp-idf/en/v6.1/esp32c3/api-reference/peripherals/gpio.html)
- [SPI master](https://docs.espressif.com/projects/esp-idf/en/v6.1/esp32c3/api-reference/peripherals/spi_master.html)
- [Sleep modes](https://docs.espressif.com/projects/esp-idf/en/v6.1/esp32c3/api-reference/system/sleep_modes.html)
- [ESP32-C3 GPIO capabilities](https://github.com/espressif/esp-idf/blob/v6.1/components/soc/esp32c3/include/soc/soc_caps.h)

The rewrite uses ESP-IDF v6.1; the references above follow that version.

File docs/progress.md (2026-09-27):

# Progress and Commit Log

This log tracks the firmware rewrite and repository milestones.

## Completed Hardware

- Working contact-information and QR-code display.
- Button-controlled navigation, animated transitions, and LCD recovery.
- Custom PCB assembly and wiring.
- Printed enclosure with top, bottom, and button pieces.

## Step 1 / Commit 1 : Hardware and Design Baseline

Date: 2026-09-20

Milestone status: complete.

Commit title: `Add hardware designs, enclosure models, and firmware rewrite plan`

Commit: `7a0ee8d`.

### Deliverables

- Repository structure for firmware, hardware, and documentation.
- Ignore rules for generated files and local development settings.
- Firmware architecture, interaction requirements, and validation plan.
- KiCad schematic, board layout, and project settings.
- Manufacturing exports for hardware revisions 1.2, 1.3, and 1.4.
- Project-local XIAO libraries and the custom through-hole footprint.
- Top-case, bottom-case, and button STL models.
- Component inventory and upstream library attribution.

## Step 2 : Minimal ESP-IDF Application

Status: complete

- [x] Set up ESP-IDF v6.1 and the ESP32-C3 development environment.
- [x] Establish the project build configuration.
- [x] Implement an increasing counter logged once per second, with a FreeRTOS task delay between messages.
- [x] Build, flash, and verify counter output on the device through the serial monitor.
- [x] Add a one-time startup log message before the loop.
- [x] Verify restart after reset and a USB power cycle.
- [x] Record build, flash, and monitor instructions in `firmware/README.md`.

## Step 3 : Button Input: Checkpoint 1

Status: raw GPIO input checkpoint complete

Commit title: `Add GPIO6 button module and raw input polling`

Commit: `e0f1294`.

- [x] Separate the button interface and implementation into `button.h` and `button.c`.
- [x] Configure GPIO6 as an input with its internal pull-up enabled.
- [x] Expose the active-low input as a boolean pressed state.
- [x] Check initialization and sample the button approximately every 10 ms.
- [x] Log only changes, using `Status: 1` for pressed and `Status: 0` for released.
- [x] Verify expected press/release reporting on the assembled board, with no repeated messages during a steady hold or idle state.

This checkpoint established raw input polling. Debouncing and release-based classification are implemented in the completed checkpoint below.

## Step 3 : Button Input: Debouncing and Gestures

Date: 2026-09-21

Status: complete

Commit title: `Add button debouncing and release-based gesture detection`

Commit: `04a4c53`.

- [x] Accept press and release transitions after 30 ms of stable input.
- [x] Classify presses shorter than 900 ms as short and presses of at least 900 ms as long.
- [x] Emit one gesture event on release, with no repeated gestures while held.
- [x] Ignore gesture classification for a button already held at startup.
- [x] Log startup, accepted presses, and classified releases through the serial monitor.
- [x] Pass simulated bounce, threshold, startup-held, and reinitialization checks.
- [x] Build with ESP-IDF v6.1 and verify expected operation after flashing the board.

Validation results are recorded in [testing.md](testing.md). This checkpoint established gesture logging before display integration.

## Step 4 : Display Driver and Diagnostics

Date: 2026-09-22

Commit title: `Add ILI9488 display driver and startup diagnostics`

Commit: `632c107`.

Status: complete

- [x] Configure SPI2 and LCD control pins as a separate component.
- [x] Separate bus setup from repeatable panel initialization.
- [x] Implement RGB666 color fills and bounded rectangle drawing.
- [x] Add startup color, corner, line, and invalid-coordinate diagnostics.
- [x] Build successfully and pass simulated transfer/error-path checks.
- [x] Verify the color sequence and record physical corner positions: blue top-left, red top-right, white bottom-left, green bottom-right.
- [x] Verify edge drawing on the LCD.
- [x] Verify at least five cold starts and button logging after diagnostics.

## Step 5 : Embedded Images and Slide Navigation

Date: 2026-09-22

Commit title: `Add embedded slides and short-press navigation`

Commit: `876373f`.

Status: complete

- [x] Add the original business-card and QR artwork with reproducible RGB assets.
- [x] Convert 480 x 320 artwork to native 320 x 480 RGB888 without resizing.
- [x] Embed both slides in flash and validate image lengths before drawing.
- [x] Stream RGB666 pixels through the existing 960-byte row buffer.
- [x] Show the business card at startup and wrap navigation on short releases.
- [x] Retain the current slide index if a draw fails.
- [x] Add a 2 MB application partition and optional startup diagnostics.
- [x] Pass converter, rendering, and simulated navigation checks.
- [x] Build with ESP-IDF v6.1, including a fresh configuration with diagnostics enabled.
- [x] Flash the application and updated partition table with verified data hashes.
- [x] Match the QR background to the business card and verify its translucent panel appearance on the display.
- [x] Verify readable artwork, correct orientation, and one slide change per short press.
- [x] Verify at least 20 slide changes, wraparound, and no navigation on long holds.
- [x] Scan the displayed QR code and confirm its destination.
- [x] Verify five cold starts.
- [x] Record numerical draw-time and heap results in the release validation record.

## Step 6 : LCD Recovery and Transitions

Date: 2026-09-22

Status: complete

- [x] Recover the LCD on long release without recreating the SPI bus.
- [x] Redraw the selected slide without advancing it during recovery.
- [x] Add incremental black wipe and shuffled 8 x 8 tile reveal.
- [x] Preserve the QR background and translucent panel in every tile.
- [x] Sample input between bounded animation steps and record accepted activity.
- [x] Discard gestures during drawing and require a stable release before rearming.
- [x] Preserve the selected slide and stop animation on transfer failure.
- [x] Pass integrated checks with the actual button, controller, transition, and slide code.
- [x] Verify 20 simulated transitions with complete tile coverage and expected final pixels.
- [x] Build with ESP-IDF v6.1.
- [x] Flash the recovery and transition firmware with verified data hashes.
- [x] Verify LCD-only power-cycle recovery on both slides.
- [x] Verify 20 transitions and presses held across the animation boundary on hardware.
- [x] Check transition timing, input-sampling gaps, and heap readings on hardware.
- [x] Confirm QR scanning after transition and recovery.

## Step 7 : Inactivity Sleep and Button Wake

Date: 2026-09-22

Commit title: `Add LCD recovery, transitions, and inactivity sleep`

Status: complete

Hardware validation completed: 2026-09-27

- [x] Start the 300-second timeout after drawing and reset it on accepted input.
- [x] Defer sleep during held input, rendering, and recovery.
- [x] Add panel sleep with 120 ms settling and input cancellation.
- [x] Configure ordinary light sleep with GPIO6 wake and retained pull-up.
- [x] Restore the selected slide using the existing SPI bus.
- [x] Consume the wake gesture until a stable release.
- [x] Restart inactivity after wake, cancellation, or failed restoration.
- [x] Pass timeout, cancellation, error-path, and ten simulated sleep/wake cycles.
- [x] Build with ESP-IDF v6.1 with diagnostics disabled and enabled.
- [x] Flash the sleep/wake firmware with verified data hashes.
- [x] Verify the full five-minute timeout on hardware.
- [x] Verify ten sleep/wake cycles on both slides and long-held wake suppression.
- [x] Verify sleep deferral and cancellation during button activity.
Current consumption and physical wake latency are outside this release's measurement scope.

## Step 8 : Release Validation

Status: in progress

- [x] Complete the remaining functional hardware acceptance checks.
- [x] Confirm the clean-checkout build workflow.
- [x] Record startup drawing, transition timing, sampling gaps, and heap measurements.
- [x] Add device photographs and a demonstration.

## Upcoming Milestones

| Step | Scope | Status |
|---|---|---|
| 3 | Button input, debouncing, and press classification | Complete |
| 4 | Display initialization, drawing, and orientation | Complete |
| 5 | Embedded images and slide navigation | Complete |
| 6 | LCD recovery and incremental animated transitions | Complete |
| 7 | Inactivity timeout, light sleep, and button wake-up | Complete |
| 8 | Reproducible builds, measurements, and release validation | In progress |

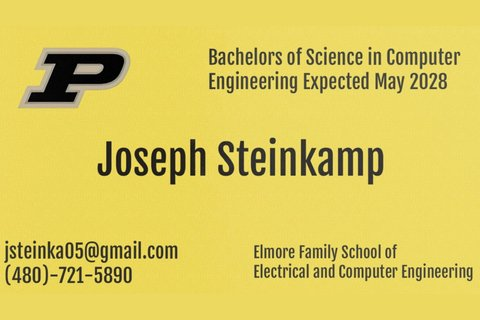
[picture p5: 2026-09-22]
firmware/images/business_card.png

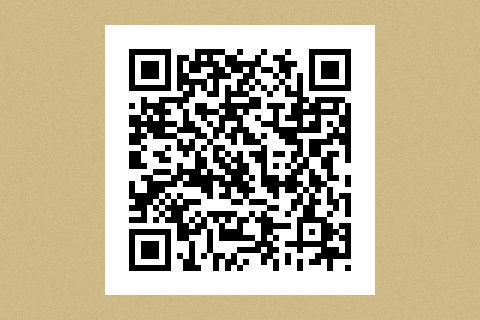
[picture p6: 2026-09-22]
firmware/images/linkedin_qr.png

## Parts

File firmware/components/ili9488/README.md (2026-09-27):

# ILI9488 Display Driver

The driver configures SPI2 at 20 MHz in mode 0 and uses native 320 x 480 coordinates. It exposes separate bus and panel initialization, bounded rectangle drawing, full-screen fills, and packed RGB888 image drawing.

## Interface

| Function | Purpose |
|---|---|
| `ili9488_bus_init` | Configure DC/RESET and register the SPI device once |
| `ili9488_panel_init` | Reset/configure the LCD using the existing bus |
| `ili9488_panel_sleep` | Send display-off and sleep-in commands; invalidate drawing readiness |
| `ili9488_fill_rect` | Fill a fully contained rectangle; reject invalid bounds |
| `ili9488_fill_screen` | Fill the whole panel using the rectangle implementation |
| `ili9488_draw_rgb888` | Stream packed RGB888 rows into a bounded rectangle |

The driver returns errors to its caller. Negative coordinates, nonpositive dimensions, and out-of-bounds rectangles return `ESP_ERR_INVALID_ARG`. Valid drawing before panel initialization returns `ESP_ERR_INVALID_STATE`. Repeated bus initialization is rejected; repeated panel initialization reuses the connection.

Panel sleep sends `0x28` followed by `0x10`. It returns without waiting; the caller must allow at least 120 ms before processor sleep or panel reinitialization. Drawing remains blocked until a successful `ili9488_panel_init`, including when a sleep command fails. The power manager handles that interval while continuing button polling. Sleep commands do not switch off the directly powered backlight.

## Pixel Transfers

Colors are supplied as RGB888 channels and masked to their upper six bits for RGB666 transmission. A static DMA-capable 960-byte buffer holds one row; narrower rectangles send only their actual row length. No full-screen framebuffer is allocated. Image drawing requires exactly `width * height * 3` bytes and returns `ESP_ERR_INVALID_SIZE` for any other length. Null pixel pointers and invalid bounds are rejected before sending commands. Source pixels remain unchanged.

All calls must run in one task. Drawing is synchronous, so button sampling pauses during display initialization and diagnostics. The transition module returns to input sampling between bounded drawing steps. Panel reset and full recovery drawing remain synchronous.

## Startup Diagnostic

The application configures the bus, checks that drawing before panel initialization is rejected, and initializes the panel. When the optional startup diagnostic is enabled, it checks invalid rectangles and repeated bus initialization, displays black/red/green/blue/white fills, reinitializes the panel, and shows a corner pattern for five seconds. The first embedded slide is then drawn and button polling begins. Diagnostics default off in the slide firmware.

Native-coordinate markers:

- Red: (0, 0); green: (300, 0).
- Blue: (0, 460); white: (300, 460).
- Each marker is 20 x 20 pixels.
- Center: yellow 80 x 40 rectangle.
- Cyan horizontal line: y=120, full width.
- Magenta vertical line: x=80, full height.

Observed physical corner mapping (2026-09-22): top-left blue, top-right red, bottom-left white, bottom-right green. These positions map the native coordinates to the tested physical orientation.

## Validation

The firmware builds and the driver passes local simulated SPI/GPIO tests for configuration, initialization order, bounds, pixel data, and error propagation. The color sequence and corner positions were confirmed on the LCD. Edge rendering and repeated cold starts remain to be verified. MISO is disconnected, so successful transfers cannot confirm the panel's visible output.

After flashing, inspect each fill and pattern, confirm button logs resume, and repeat at least five full power cycles with LCD power on. Record actual results in `docs/testing.md`.

The reset delays and register values follow the working prototype: MADCTL `0x88`, COLMOD `0x66`, and conservative reset/sleep-out waits.

- [ILI9488 register and timing reference](https://files.waveshare.com/upload/2/2d/ILI9488_Data_Sheet.pdf)
- [ESP-IDF v6.1 SPI master API](https://docs.espressif.com/projects/esp-idf/en/v6.1/esp32c3/api-reference/peripherals/spi_master.html)

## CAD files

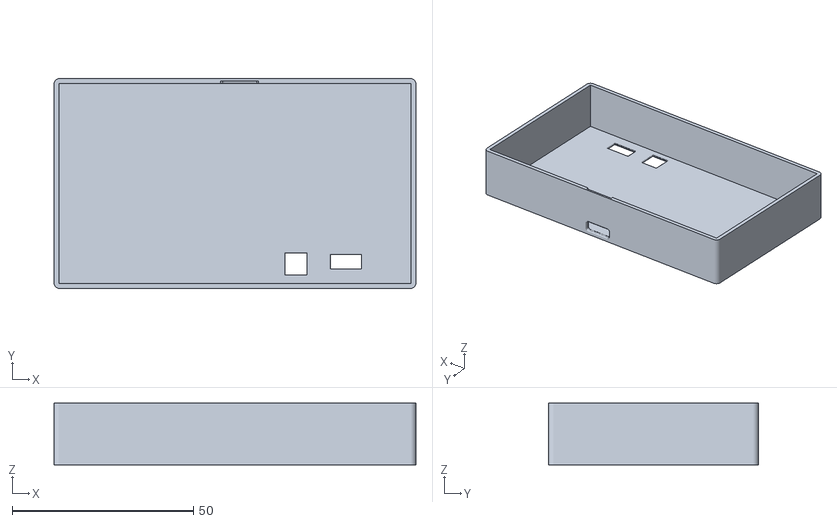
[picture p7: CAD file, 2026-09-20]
hardware/enclosure/Bottom_Case.stl
99.9 x 57.9 x 17.1

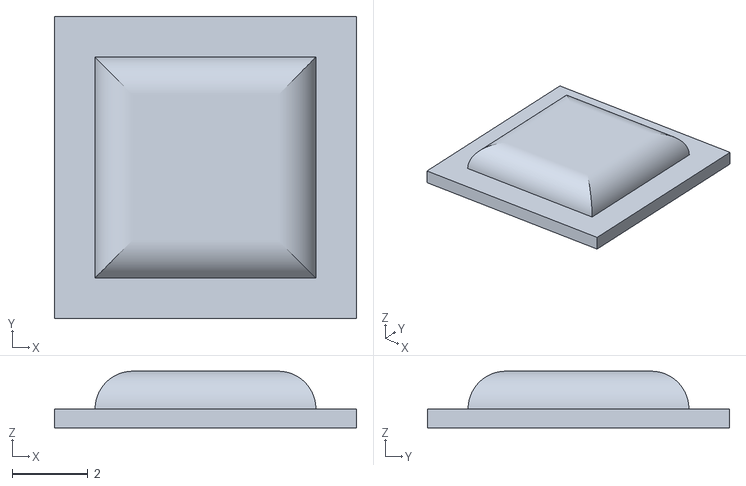
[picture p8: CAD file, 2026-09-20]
hardware/enclosure/Button (1).stl
8.00 x 8.00 x 1.50

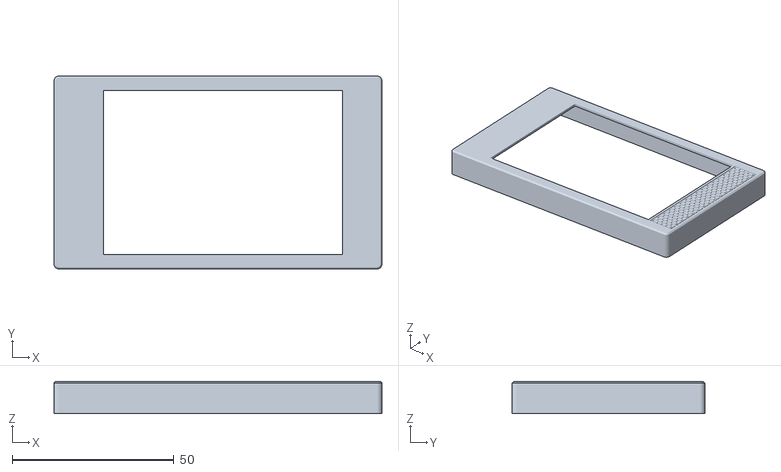
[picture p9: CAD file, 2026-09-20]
hardware/enclosure/Top_Case.stl
101.2 x 59.5 x 10.0

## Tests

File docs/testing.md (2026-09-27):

# Firmware Validation

## Button Input : 2026-09-21

Environment: ESP-IDF v6.1, ESP32-C3 target, Seeed Studio XIAO ESP32-C3.

### Build

The application builds and links successfully with the GPIO and timer components. This verifies compilation; physical behavior is recorded separately below.

### Simulated Input

The current `button.c` was compiled for RISC-V and executed in QEMU with GPIO configuration and input stubs. Tests supplied explicit readings and timestamps to the actual button implementation. These tests exercise software logic, not electrical behavior or FreeRTOS scheduling. The test harness is local and is not included in this repository.

| Check | Result |
|---|---|
| Active-low reading and GPIO6 input configuration | Passed |
| Candidate rejected at 29,999 us and accepted at 30,000 us | Passed |
| Bounce restarts the stability interval on press and release | Passed |
| No repeated events while held or after a completed release | Passed |
| 899 ms press classified short | Passed |
| 900 ms and 901 ms presses classified long | Passed |
| Long hold produces its gesture only on release | Passed |
| Button held at startup releases without a short/long gesture | Passed |
| A normal gesture works after releasing the startup-held button | Passed |
| Reinitialization clears an unfinished gesture | Passed |

### Hardware

Expected button operation was verified after flashing the assembled board. Earlier raw-input testing established press/release detection and quiet output during steady hold and idle states. Exact timing-boundary results above come from simulated timestamps, not hand-timed physical presses.

### Remaining Validation

- Reset and USB power-cycle behavior from the application-foundation checklist.
- Display navigation and recovery after gesture events are connected to the display driver.
- Sleep/wake behavior and current measurements in the later power-management stage.

## Display Driver : 2026-09-21

Status: code implemented; physical display validation remaining.

The complete application builds with ESP-IDF v6.1. A local RISC-V/QEMU harness executes the actual display driver with stubbed GPIO, SPI, and delays. This verifies software behavior without simulating the LCD's optical output or electrical timing. The harness remains local.

| Simulated check | Result |
|---|---|
| GPIO mapping, SPI mode/speed, DMA selection, and transfer limit | Passed |
| Reset levels/delays and ordered panel commands/parameters | Passed |
| Repeated bus initialization rejected; panel reinitialization reuses bus | Passed |
| Drawing before panel initialization rejected | Passed |
| Negative, zero, overflowing, and out-of-range rectangles produce no transfers | Passed |
| Last-pixel address bytes and inclusive endpoints | Passed |
| RGB666 channel masking and narrow-row byte counts | Passed |
| Full-screen fill sends 480 rows of 960 bytes | Passed |
| GPIO/SPI errors stop the operation and propagate to the caller | Passed |
| Failed panel initialization prevents subsequent drawing | Passed |
| Failed device registration releases the owned bus; failed cleanup blocks duplicate setup | Passed |

The display firmware was flashed and verified on COM4. On 2026-09-22, the color sequence was confirmed working and the physical corner positions were reported as follows:

| Physical corner | Marker |
|---|---|
| Top-left | Blue |
| Top-right | Red |
| Bottom-left | White |
| Bottom-right | Green |

The single yellow-pixel visual marker was subsequently removed. Simulated last-pixel bounds and byte-order checks remain valid. Edge rendering, five cold starts, and button logging after diagnostics still require confirmation. The marker removal is included in the flashed slide firmware; startup diagnostics are disabled by default.

## Embedded Images and Navigation : 2026-09-22

Status: software checks passed; hardware validation pending.

### Build and Storage

The default ESP-IDF v6.1 build produces a 1,109,792-byte application in a 2,097,152-byte factory partition, leaving 987,360 bytes free. Both image symbols reside in `.flash.rodata`, each spanning exactly 460,800 bytes. The renderer reuses the existing 960-byte DRAM buffer. QR recoloring adds a 960-byte stack row; neither path allocates a full-screen framebuffer.

These are build-time measurements. Runtime free heap, minimum heap, largest free internal block, and draw duration are logged after successful draws but have not yet been measured on hardware for this version.

A separate build from fresh generated configuration also passed with startup diagnostics enabled. It selected the custom partition table from defaults. Normal operation was built with diagnostics disabled.

### Software Checks

| Check | Result |
|---|---|
| Converter rotation, RGB channel order, and exact output length | Passed |
| Invalid source dimensions rejected without changing existing output | Passed |
| Transparent pixels composited onto white | Passed |
| Source file protected from being used as the output | Passed |
| Both PNG sources reproduce their tracked RGB files exactly | Passed |
| Converted assets match the working prototype's raw images byte for byte | Passed |
| Full-screen and narrow-rectangle pixel order, masking, and row lengths | Passed |
| Source pixels remain unchanged after rendering | Passed |
| Null data, malformed lengths, invalid bounds, and uninitialized panel rejected | Passed |
| Command and pixel-transfer failures stop rendering | Passed |
| Slide count, invalid indices, and malformed embedded image lengths | Passed |
| Startup selects the business card; short releases advance and wrap | Passed |
| Press, untracked release, and long-release events do not navigate | Passed |
| Failed drawing preserves the selected index for the next navigation attempt | Passed |

Converter tests are included under `firmware/tools/tests` and run with `python -m unittest discover -s tools/tests -v` from `firmware`. Local RISC-V/QEMU harnesses exercise the actual driver, slide metadata, and application code with peripheral/event stubs. The application harness supplies button events directly; debounce timing is covered by the earlier input tests. These checks do not establish LCD output, physical QR readability, or real-time input handling during transfers.

### Hardware Acceptance

The application, bootloader, and updated partition table were flashed on COM4 on 2026-09-22. Written data hashes were verified and the board was reset. The revised QR background and translucent panel appearance were confirmed on the display. Remaining hardware checks:

- Confirm readable, correctly oriented business-card artwork at startup.
- Perform at least 20 short presses, checking exactly one change on each release and wraparound between both slides.
- Hold for more than 900 ms and confirm release logs without changing the slide.
- Scan the displayed QR and confirm the intended LinkedIn destination.
- Perform five full power cycles with LCD power on; confirm the business-card slide returns each time.
- Record draw duration and free/minimum/largest-block heap values after startup and repeated navigation.
- Enable startup diagnostics and finish the earlier edge-rendering and post-diagnostic button checks.

Synchronous drawing pauses button polling. Complete gestures during that interval may be missed. LCD recovery, incremental rendering, and input handling during animated transitions remain later-stage work.

### QR Background Update

The QR slide now composites the original black pattern over a 25-percent white panel on the business card's gold background. Local tests check every composited row against the expected gold and black colors, slide wraparound, malformed QR asset rejection, and failures on the first and middle rows. The source images remain unchanged. The revised appearance was confirmed on the display after reflashing. Physical QR scanning remains open.

The build-size measurements above include this QR update. Converter tests also verify that the original black-and-white panel retains a 24-pixel quiet border on all sides and reject multi-frame artwork.

## LCD Recovery and Transitions : 2026-09-22

Status: complete; software and hardware checks passed.

### Build and Memory

The standard ESP-IDF v6.1 build produces a 1,111,632-byte application in the existing 2,097,152-byte partition, leaving 985,520 bytes free. The linker places the 4,800-byte tile-order array in DRAM. Drawing uses a 192-byte stack tile and the existing 960-byte driver buffer. Full QR redraws retain their separate 960-byte stack row. No full-screen framebuffer is allocated in the firmware.

Builds passed with startup diagnostics both disabled and enabled. The application logs initial drawing duration, transition duration, longest observed input-sampling interval, and heap readings. Timing and heap checks passed during hardware testing. This record contains pass/fail results rather than numerical readings. Panel reset, startup drawing, and recovery drawing remain synchronous.

### Integrated Software Checks

A local RISC-V/QEMU harness compiles the actual button, application controller, transitions, and slides modules. Synthetic raw button readings and timestamps pass through the real debounce logic. Stubbed LCD operations reconstruct output pixels and inject errors; they do not emulate electrical timing or the LCD's response to power loss. The harness remains local.

| Check | Result |
|---|---|
| Startup image and startup-held button release behavior | Passed |
| Invalid slide indices, region bounds, lengths, and null buffers | Passed |
| Malformed embedded artwork rejected before drawing | Passed |
| Twenty repeated transitions produce the expected final pixels | Passed |
| All 2,400 tiles drawn exactly once per completed reveal | Passed |
| QR tiles preserve the gold background, translucent panel, and black modules | Passed |
| One wipe strip or at most sixteen tiles per update | Passed |
| Early update does no work; delayed update does not catch up in a burst | Passed |
| Input wholly inside animation updates activity without queuing an action | Passed |
| A held press spanning completion is consumed until a stable release | Passed |
| A raw press first sampled after the final step is also suppressed | Passed |
| Long release reinitializes the panel and redraws either selected slide | Passed |
| Recovery preserves slide selection and does not recreate the SPI bus | Passed |
| Panel failure prevents redraw; a later recovery can succeed | Passed |
| Wipe/tile failure stops animation without advancing the selected slide | Passed |
| Recovery restores the selected image after a failed transition | Passed |
| Controller reinitialization cancels unfinished animation | Passed |

### Hardware Acceptance

This version was flashed on COM4 on 2026-09-22. Written data hashes were verified and the board was reset. Hardware checks were confirmed successful on the assembled device:

| Check | Result |
|---|---|
| LCD-only power-cycle recovery restores the selected slide | Passed |
| Repeated transitions complete without residual strips or tiles | Passed |
| Gestures during animation do not queue navigation or recovery | Passed |
| Holds spanning animation completion are consumed until release | Passed |
| A fresh gesture works after the release gate clears | Passed |
| QR scanning after transition and recovery | Passed |
| Transition timing, input-sampling gaps, and heap checks | Passed |

These results cover recovery and animation. The separate cold-start checks from earlier milestones remain open.

## Inactivity Sleep and Wake : 2026-09-22

Status: complete; software and hardware checks passed.

Software validation repeated on 2026-09-27: both ESP-IDF build configurations, power-manager and display-driver simulations, integrated navigation/recovery/sleep checks, malformed-asset rejection, and all seven image-converter tests passed.

### Build and Software Checks

The normal ESP-IDF v6.1 build produces a 1,121,456-byte application in the existing 2,097,152-byte partition, leaving 975,696 bytes free. Builds passed with startup diagnostics disabled and enabled. No full-screen framebuffer was added.

Local RISC-V/QEMU checks exercise the actual power manager, button, controller, transition, slide, and display-driver code. Sleep and peripherals are stubbed; these checks establish state handling and command sequencing, not real power consumption, electrical wake behavior, or LCD sleep timing.

| Check | Result |
|---|---|
| No entry at 299,999,999 us; entry begins at 300,000,000 us | Passed |
| Accepted input extends inactivity; held input and rendering defer entry | Passed |
| Stable raw release required before entry | Passed |
| Display-off precedes sleep-in; drawing blocked until panel reinitialization | Passed |
| 120 ms settling completes before processor sleep or restoration | Passed |
| Brief raw press or accepted activity during settling cancels entry | Passed |
| Fresh pin checks prevent entry with an already pressed button | Passed |
| Wake configuration failures and panel command errors propagate | Passed |
| Rejected sleep restores the panel and restarts inactivity | Passed |
| Ten simulated wake cycles preserve selection and expected pixels across both slides | Passed |
| Long-held wake gesture is consumed; a fresh gesture works after release | Passed |
| Failed restoration preserves selection and permits later manual recovery | Passed |
| Existing twenty-transition, QR composition, and recovery regressions | Passed |

### Hardware Acceptance

The sleep/wake firmware was flashed on COM4 on 2026-09-22. Written data hashes were verified and the board was reset. Hardware acceptance checks were confirmed complete on 2026-09-27. Functional sleep/wake checks are complete. Current consumption and physical wake latency are outside this release's measurement scope.

- [x] Leave each slide idle for the full 300 seconds and verify entry without a premature timeout.
- [x] Press before timeout and confirm a fresh five-minute interval after accepted activity.
- [x] Hold the button through timeout and confirm sleep is deferred.
- [x] Complete at least ten sleep/wake cycles across both slides with LCD power on.
- [x] Confirm a brief wake press restores the same slide without navigation.
- [x] Hold the wake button longer than 900 ms and confirm release does not trigger recovery or navigation.
- [x] Confirm a fresh short press and long-press recovery still work after waking.
- [x] Press during the panel-settling interval and verify restoration without an extra action.
- [x] Scan the QR after waking and check for residual or missing pixels.

The directly powered backlight remains on. Display sleep does not disconnect its supply, and software checks do not establish a numerical power reduction. Redraw logs measure panel initialization plus rendering after sleep returns; they are not a complete wake-latency measurement.

## Release Validation : 2026-09-27

All remaining functional hardware checks are confirmed complete, including reset and USB power-cycle behavior, five cold starts, display-edge rendering, and button operation after diagnostics. This supersedes earlier pending functional hardware entries. The clean-checkout build workflow is also confirmed complete. Timing and heap results are recorded below. Device media is included in the project and hardware documentation. Current consumption and physical wake latency are outside this release's measurement scope.

## Recorded Timing and Memory : 2026-09-27

Device: assembled XIAO ESP32-C3 card, USB connected to the host PC, ESP-IDF v6.1, normal display configuration with startup diagnostics disabled. Supply voltage was not measured. Five USB-triggered resets were followed by twenty manually triggered short-press transitions, allowing each animation to finish before the next press. These resets are not supply power cycles.

The firmware source corresponds to `fe8d997`. The existing flashed build reports `876373f-dirty` because it was compiled before that source was committed. Its logged ELF hash prefix matches the local ELF SHA-256 `7b347ccf140ae9c73c867ccd0ec7c1dc2d91cb9715d84b2629d5b310d8041b46`.

| Measurement | Samples | Result |
|---|---|---|
| Initial slide drawing | 5 resets | 238 ms on every run |
| Transition duration | 20 transitions | 2604.8 ms average; 2556–2676 ms range |
| Largest logged input-sampling gap during transitions | 20 transitions | 10004 us |
| Free heap after startup and completed transitions | 5 startup + 20 transition readings | 315,072 bytes at every reading |
| Minimum-ever free heap at those readings | Same samples | 315,072 bytes |
| Largest free internal allocation block | Same samples | 180,224 bytes |

Initial drawing time excludes earlier boot and panel initialization. Transition durations include the scheduled animation delays and drawing work. Sampling-gap results describe this run rather than a guaranteed worst-case bound. Unchanged heap readings show no observed growth in allocated heap during this test; they do not prove the absence of every memory defect. The captured logs contain no reported operation failures.

Whole-device current, supply voltage, and physical button-to-image wake latency were not measured by this serial capture. Raw captures and collection scripts are retained locally.

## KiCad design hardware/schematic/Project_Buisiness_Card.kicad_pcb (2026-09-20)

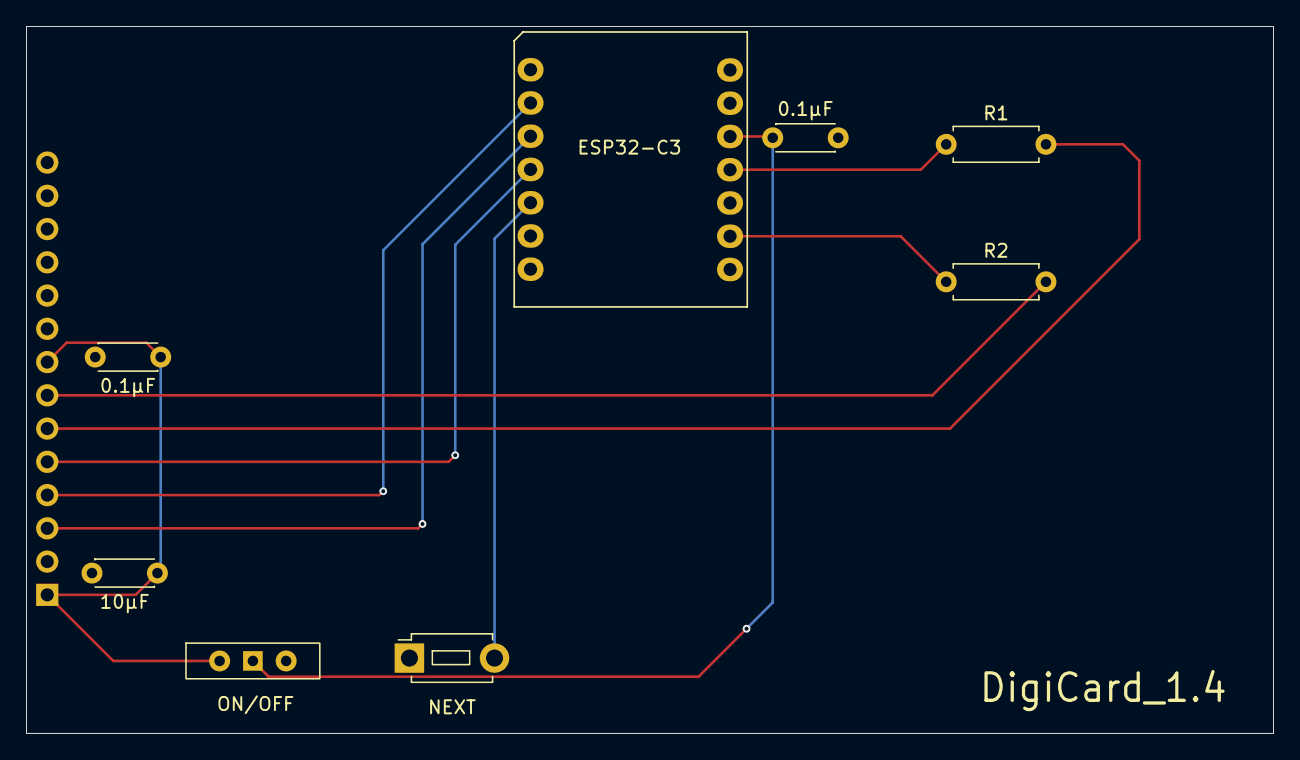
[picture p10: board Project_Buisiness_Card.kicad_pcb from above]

Board: 2 copper layers, 95.2 x 54.0 mm, 9 parts (1 on the bottom side), 11 nets.

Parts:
0.1μF, 0.1μF#2: 0.1u; C_Disc_D4.3mm_W1.9mm_P5.00mm
10μF: 10u; C_Disc_D4.3mm_W1.9mm_P5.00mm
J_LCD1: Conn_01x14; PinHeader_1x14_P2.54mm_Vertical
NEXT: SW_Push; SW_PUSH_1P1T_6x3.5mm_H4.3_APEM_MJTP1243
R1, R2: 46; R_Axial_DIN0207_L6.3mm_D2.5mm_P7.62mm_Horizontal
SW1: SW_SPST; SW_Slide-03_Wuerth-WS-SLTV_10x2.5x6.4_P2.54mm
U1: XIAO ESP32C3; MOUDLE14P-SMD-2.54-21X17.8MM

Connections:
GND: 0.1μF.2, 0.1μF#2.2, 10μF.2, J_LCD1.2, NEXT.1, U1.13 (GND)
unnamed: 0.1μF.1, 10μF.1, J_LCD1.1, J_LCD1.8, SW1.2 (B)
unnamed: J_LCD1.3, U1.3 (D2)
unnamed: J_LCD1.4, U1.2 (D1)
unnamed: J_LCD1.5, U1.4 (D3)
unnamed: J_LCD1.6, R1.2
unnamed: J_LCD1.7, R2.2
unnamed: 0.1μF#2.1, SW1.1 (A), U1.12 (VCC_3V3)
unnamed: NEXT.2, U1.5 (D4)
unnamed: R2.1, U1.9 (D8)
unnamed: R1.1, U1.11 (D10)

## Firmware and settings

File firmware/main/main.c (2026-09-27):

#include "freertos/FreeRTOS.h"
#include "freertos/task.h"
#include "esp_log.h"
#include "esp_timer.h"
#include "button.h"
#include "ili9488.h"
#include "display_diagnostics.h"
#include "esp_system.h"
#include "esp_heap_caps.h"
#include "sdkconfig.h"
#include "app_controller.h"
#include "transitions.h"
#include "power_manager.h"

static const char *TAG = "business_card";

static void log_memory(void)
{
    ESP_LOGI(TAG, "Free heap: %lu, minimum: %lu, largest internal block: %u",
             (unsigned long)esp_get_free_heap_size(),
             (unsigned long)esp_get_minimum_free_heap_size(),
             (unsigned)heap_caps_get_largest_free_block(MALLOC_CAP_INTERNAL | MALLOC_CAP_8BIT));
}

void app_main(void)
{
    ESP_ERROR_CHECK(button_init());
    ESP_ERROR_CHECK(power_manager_init());
    ESP_LOGI(TAG, "Button input ready");

    // Set up the SPI connection before the panel
    ESP_ERROR_CHECK(ili9488_bus_init());
    // Drawing must be rejected until the panel is initialized
    if (ili9488_fill_rect(0, 0, 1, 1, 0, 0, 0) != ESP_ERR_INVALID_STATE) {
        ESP_LOGE(TAG, "Uninitialized drawing check failed");
        ESP_ERROR_CHECK(ESP_FAIL);
    }
    ESP_ERROR_CHECK(ili9488_panel_init());
    ESP_LOGI(TAG, "LCD ready");
    // Keep the color checks available without running them every startup
#if CONFIG_BUSINESS_CARD_DISPLAY_DIAGNOSTICS
    ESP_ERROR_CHECK(display_diagnostics_run());
    vTaskDelay(pdMS_TO_TICKS(5000));
#endif
    int64_t started_us = esp_timer_get_time();
    ESP_ERROR_CHECK(app_controller_init(started_us));
    app_controller_reset_activity(esp_timer_get_time());
    ESP_LOGI(TAG, "Initial slide ready in %lld ms",
             (long long)((esp_timer_get_time() - started_us) / 1000));
    log_memory();
    int64_t previous_sample_us = esp_timer_get_time();
    int64_t transition_started_us = 0;
    int64_t longest_gap_us = 0;
    int64_t transition_duration_us = 0;
    bool report_transition = false;
    ESP_LOGI(TAG, "Button monitoring active");

    // Resume button sampling after display startup finishes
    while (true) {
        bool raw_pressed = button_is_pressed();
        int64_t now_us = esp_timer_get_time();
        button_event_t event = button_update(raw_pressed, now_us);
        bool was_active = transitions_is_active();
        if ((was_active || report_transition) && now_us - previous_sample_us > longest_gap_us) {
            longest_gap_us = now_us - previous_sample_us;
        }
        previous_sample_us = now_us;
        if (report_transition) {
            // Wait for this sample to include the final step and task delay
            ESP_LOGI(TAG, "Transition ended in %lld ms, longest sampled gap %lld us",
                     (long long)(transition_duration_us / 1000),
                     (long long)longest_gap_us);
            log_memory();
            report_transition = false;
        }

        switch (event) {
        case BUTTON_EVENT_PRESSED:
            ESP_LOGI(TAG, "Button pressed");
            break;
        case BUTTON_EVENT_RELEASED:
            ESP_LOGI(TAG, "Button released (no tracked press)");
            break;
        case BUTTON_EVENT_SHORT_PRESS:
            ESP_LOGI(TAG, "Short press released");
            break;
        case BUTTON_EVENT_LONG_PRESS:
            ESP_LOGI(TAG, "Long press released");
            break;
        case BUTTON_EVENT_NONE:
            break;
        }

        esp_err_t result = app_controller_update(event, raw_pressed, now_us);
        if (result != ESP_OK) {
            ESP_LOGE(TAG, "Display operation failed: %s", esp_err_to_name(result));
        }
        if (!was_active && transitions_is_active()) {
            transition_started_us = now_us;
            longest_gap_us = 0;
        } else if (was_active && !transitions_is_active()) {
            transition_duration_us = esp_timer_get_time() - transition_started_us;
            report_transition = true;
        }
        vTaskDelay(pdMS_TO_TICKS(10));
    }
}

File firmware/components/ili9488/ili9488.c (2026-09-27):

#include "ili9488.h"
#include "driver/gpio.h"
#include "driver/spi_master.h"
#include <stdbool.h>
#include <stddef.h>
#include "esp_attr.h"
#include "freertos/FreeRTOS.h"
#include "freertos/task.h"

// LCD connections on the assembled PCB
static const gpio_num_t LCD_SCK = GPIO_NUM_8;
static const gpio_num_t LCD_MOSI = GPIO_NUM_10;
static const gpio_num_t LCD_CS = GPIO_NUM_4;
static const gpio_num_t LCD_DC = GPIO_NUM_5;
static const gpio_num_t LCD_RESET = GPIO_NUM_3;
static const spi_host_device_t LCD_HOST = SPI2_HOST;

// Transfer size and LCD command values
enum {
    TRANSFER_BYTES = ILI9488_WIDTH * 3,
    SWRESET = 0x01,
    SLPIN = 0x10,
    SLPOUT = 0x11,
    DISPOFF = 0x28,
    DISPON = 0x29,
    CASET = 0x2A,
    PASET = 0x2B,
    RAMWR = 0x2C,
    MADCTL = 0x36,
    COLMOD = 0x3A
};

// Handle used for all LCD transfers
static spi_device_handle_t lcd_device;
// If this driver owns the SPI bus
static bool bus_initialized;
// If the panel completed its reset and configuration
static bool panel_ready;
// One row of RGB666 pixels, reused for each transfer
static DMA_ATTR uint8_t row_buffer[TRANSFER_BYTES];

static esp_err_t configure_control_pins(void)
{
    // DC selects command or data and RESET restarts the panel
    gpio_config_t control_config = {
        .pin_bit_mask = (1ULL << LCD_DC) | (1ULL << LCD_RESET),
        .mode = GPIO_MODE_OUTPUT,
        .pull_up_en = GPIO_PULLUP_DISABLE,
        .pull_down_en = GPIO_PULLDOWN_DISABLE,
        .intr_type = GPIO_INTR_DISABLE
    };

    esp_err_t result = gpio_config(&control_config);
    if (result != ESP_OK) {
        return result;
    }
    result = gpio_set_level(LCD_DC, 0);
    if (result != ESP_OK) {
        return result;
    }
    return gpio_set_level(LCD_RESET, 1);
}

static esp_err_t initialize_spi_bus(void)
{
    // Unused SPI pins are set to -1
    spi_bus_config_t bus_config = {
        .mosi_io_num = LCD_MOSI,
        .miso_io_num = -1,
        .sclk_io_num = LCD_SCK,
        .quadwp_io_num = -1,
        .quadhd_io_num = -1,
        .data4_io_num = -1,
        .data5_io_num = -1,
        .data6_io_num = -1,
        .data7_io_num = -1,
        .max_transfer_sz = TRANSFER_BYTES
    };
    return spi_bus_initialize(LCD_HOST, &bus_config, SPI_DMA_CH_AUTO);
}

static esp_err_t register_lcd_device(void)
{
    // Send at 20 MHz and let the SPI driver control CS
    spi_device_interface_config_t device_config = {
        .clock_speed_hz = 20000000,
        .mode = 0,
        .spics_io_num = LCD_CS,
        .queue_size = 1
    };
    return spi_bus_add_device(LCD_HOST, &device_config, &lcd_device);
}

esp_err_t ili9488_bus_init(void)
{
    // Prevent registering the same bus twice
    if (bus_initialized || lcd_device != NULL) {
        return ESP_ERR_INVALID_STATE;
    }
    esp_err_t result = configure_control_pins();
    if (result != ESP_OK) {
        return result;
    }
    result = initialize_spi_bus();
    if (result != ESP_OK) {
        return result;
    }
    bus_initialized = true;

    result = register_lcd_device();
    if (result != ESP_OK) {
        lcd_device = NULL;
        // Free only the bus allocated by this call
        if (spi_bus_free(LCD_HOST) == ESP_OK) {
            bus_initialized = false;
        }
        return result;
    }
    return ESP_OK;
}

static esp_err_t write_bytes(bool is_data, const uint8_t *bytes, size_t length)
{
    if (lcd_device == NULL) {
        return ESP_ERR_INVALID_STATE;
    }
    // Commands with no parameters need no data transfer
    if (length == 0) {
        return ESP_OK;
    }
    if (bytes == NULL || length > TRANSFER_BYTES) {
        return ESP_ERR_INVALID_ARG;
    }
    // DC low for commands and high for data
    esp_err_t result = gpio_set_level(LCD_DC, is_data ? 1 : 0);
    if (result != ESP_OK) {
        return result;
    }

    // SPI length is in bits, buffer length is in bytes
    spi_transaction_t transaction = {
        .length = length * 8,
        .tx_buffer = bytes
    };
    // Wait until the transfer finishes before reusing the buffer
    return spi_device_polling_transmit(lcd_device, &transaction);
}

static esp_err_t write_command(uint8_t command)
{
    return write_bytes(false, &command, 1);
}

static esp_err_t write_data(const uint8_t *data, size_t length)
{
    return write_bytes(true, data, length);
}

static esp_err_t write_command_data(uint8_t command, const uint8_t *data, size_t length)
{
    if (length > TRANSFER_BYTES || (length != 0 && data == NULL)) {
        return ESP_ERR_INVALID_ARG;
    }
    // Send the command before its parameter bytes
    esp_err_t result = write_command(command);
    if (result != ESP_OK) {
        return result;
    }
    return write_data(data, length);
}

static esp_err_t hardware_reset(void)
{
    // Reset delays retained from the working prototype
    esp_err_t result = gpio_set_level(LCD_RESET, 1);
    if (result != ESP_OK) {
        return result;
    }
    vTaskDelay(pdMS_TO_TICKS(100));
    // Pull RESET low then release it high
    result = gpio_set_level(LCD_RESET, 0);
    if (result != ESP_OK) {
        return result;
    }
    vTaskDelay(pdMS_TO_TICKS(200));
    result = gpio_set_level(LCD_RESET, 1);
    if (result != ESP_OK) {
        return result;
    }
    vTaskDelay(pdMS_TO_TICKS(300));
    return ESP_OK;
}

esp_err_t ili9488_panel_init(void)
{
    // Block drawing until every setup command succeeds
    panel_ready = false;
    if (lcd_device == NULL) {
        return ESP_ERR_INVALID_STATE;
    }
    esp_err_t result = hardware_reset();
    if (result != ESP_OK) {
        return result;
    }
    result = write_command(SWRESET);
    if (result != ESP_OK) {
        return result;
    }
    vTaskDelay(pdMS_TO_TICKS(150));
    // Wake the panel before setting its display format
    result = write_command(SLPOUT);
    if (result != ESP_OK) {
        return result;
    }
    vTaskDelay(pdMS_TO_TICKS(150));

    // Native 320 x 480 coordinates, page reversal and BGR color order
    uint8_t orientation = 0x88;
    result = write_command_data(MADCTL, &orientation, 1);
    if (result != ESP_OK) {
        return result;
    }
    vTaskDelay(pdMS_TO_TICKS(10));

    // RGB666 uses three bytes for each pixel
    uint8_t pixel_format = 0x66;
    result = write_command_data(COLMOD, &pixel_format, 1);
    if (result != ESP_OK) {
        return result;
    }
    vTaskDelay(pdMS_TO_TICKS(10));
    // Enable the display after its settings are applied
    result = write_command(DISPON);
    if (result != ESP_OK) {
        return result;
    }
    vTaskDelay(pdMS_TO_TICKS(120));
    panel_ready = true;
    return ESP_OK;
}

esp_err_t ili9488_panel_sleep(void)
{
    if (!panel_ready) {
        return ESP_ERR_INVALID_STATE;
    }
    // Block drawing even if only part of the sleep sequence succeeds
    panel_ready = false;
    esp_err_t result = write_command(DISPOFF);
    if (result != ESP_OK) {
        return result;
    }
    return write_command(SLPIN);
}
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

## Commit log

2026-09-20 Add hardware designs, enclosure models, and firmware rewrite plan
    [Bottom_Case.stl, Button (1).stl, Project_Buisiness_Card.kicad_pcb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]
2026-09-20 Add GPIO6 button module and raw input polling
2026-09-21 Add button debouncing and release-based gesture detection
    Debounce GPIO6 input over 30 ms and classify short and long presses
    on release using a 900 ms threshold.
    Handle startup-held input without generating a false gesture.
    Update progress, firmware documentation, and validation results.
    [button.c, main.c]
2026-09-22 Add ILI9488 display driver and startup diagnostics
2026-09-22 Add embedded slides and short-press navigation
    [partitions.csv]
2026-09-27 Revert "Add LCD recovery, transitions, and inactivity sleep"
    This reverts commit 37951f199644cc8b95df45c561d61adfde9694d4.
    [ili9488.c, main.c, power_manager.c]
2026-09-27 Add device photos, demonstration, and validation results
